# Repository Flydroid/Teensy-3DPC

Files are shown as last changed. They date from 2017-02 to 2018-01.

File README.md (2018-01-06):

# Teensy-3DPC 
is a 3D Printer Controller Board based on the Teensy 3.5 or 3.6.

Schematic and Layout are done in Eagle 

The hardware is still in development and this git used for sharing the development proceess.

#### Contribution to Think3dPrint3d and Esher3d for the DuetWifi Design on which, the Teensy-3DPC is partly based:

"Based on the DuetWifi by Think3dPrint3d and Esher3d, see www.duet3d.com for the original DuetWifi information. This reproduction/modification is not endorsed or supported in any way by Think3dPrint3d or Escher3d".



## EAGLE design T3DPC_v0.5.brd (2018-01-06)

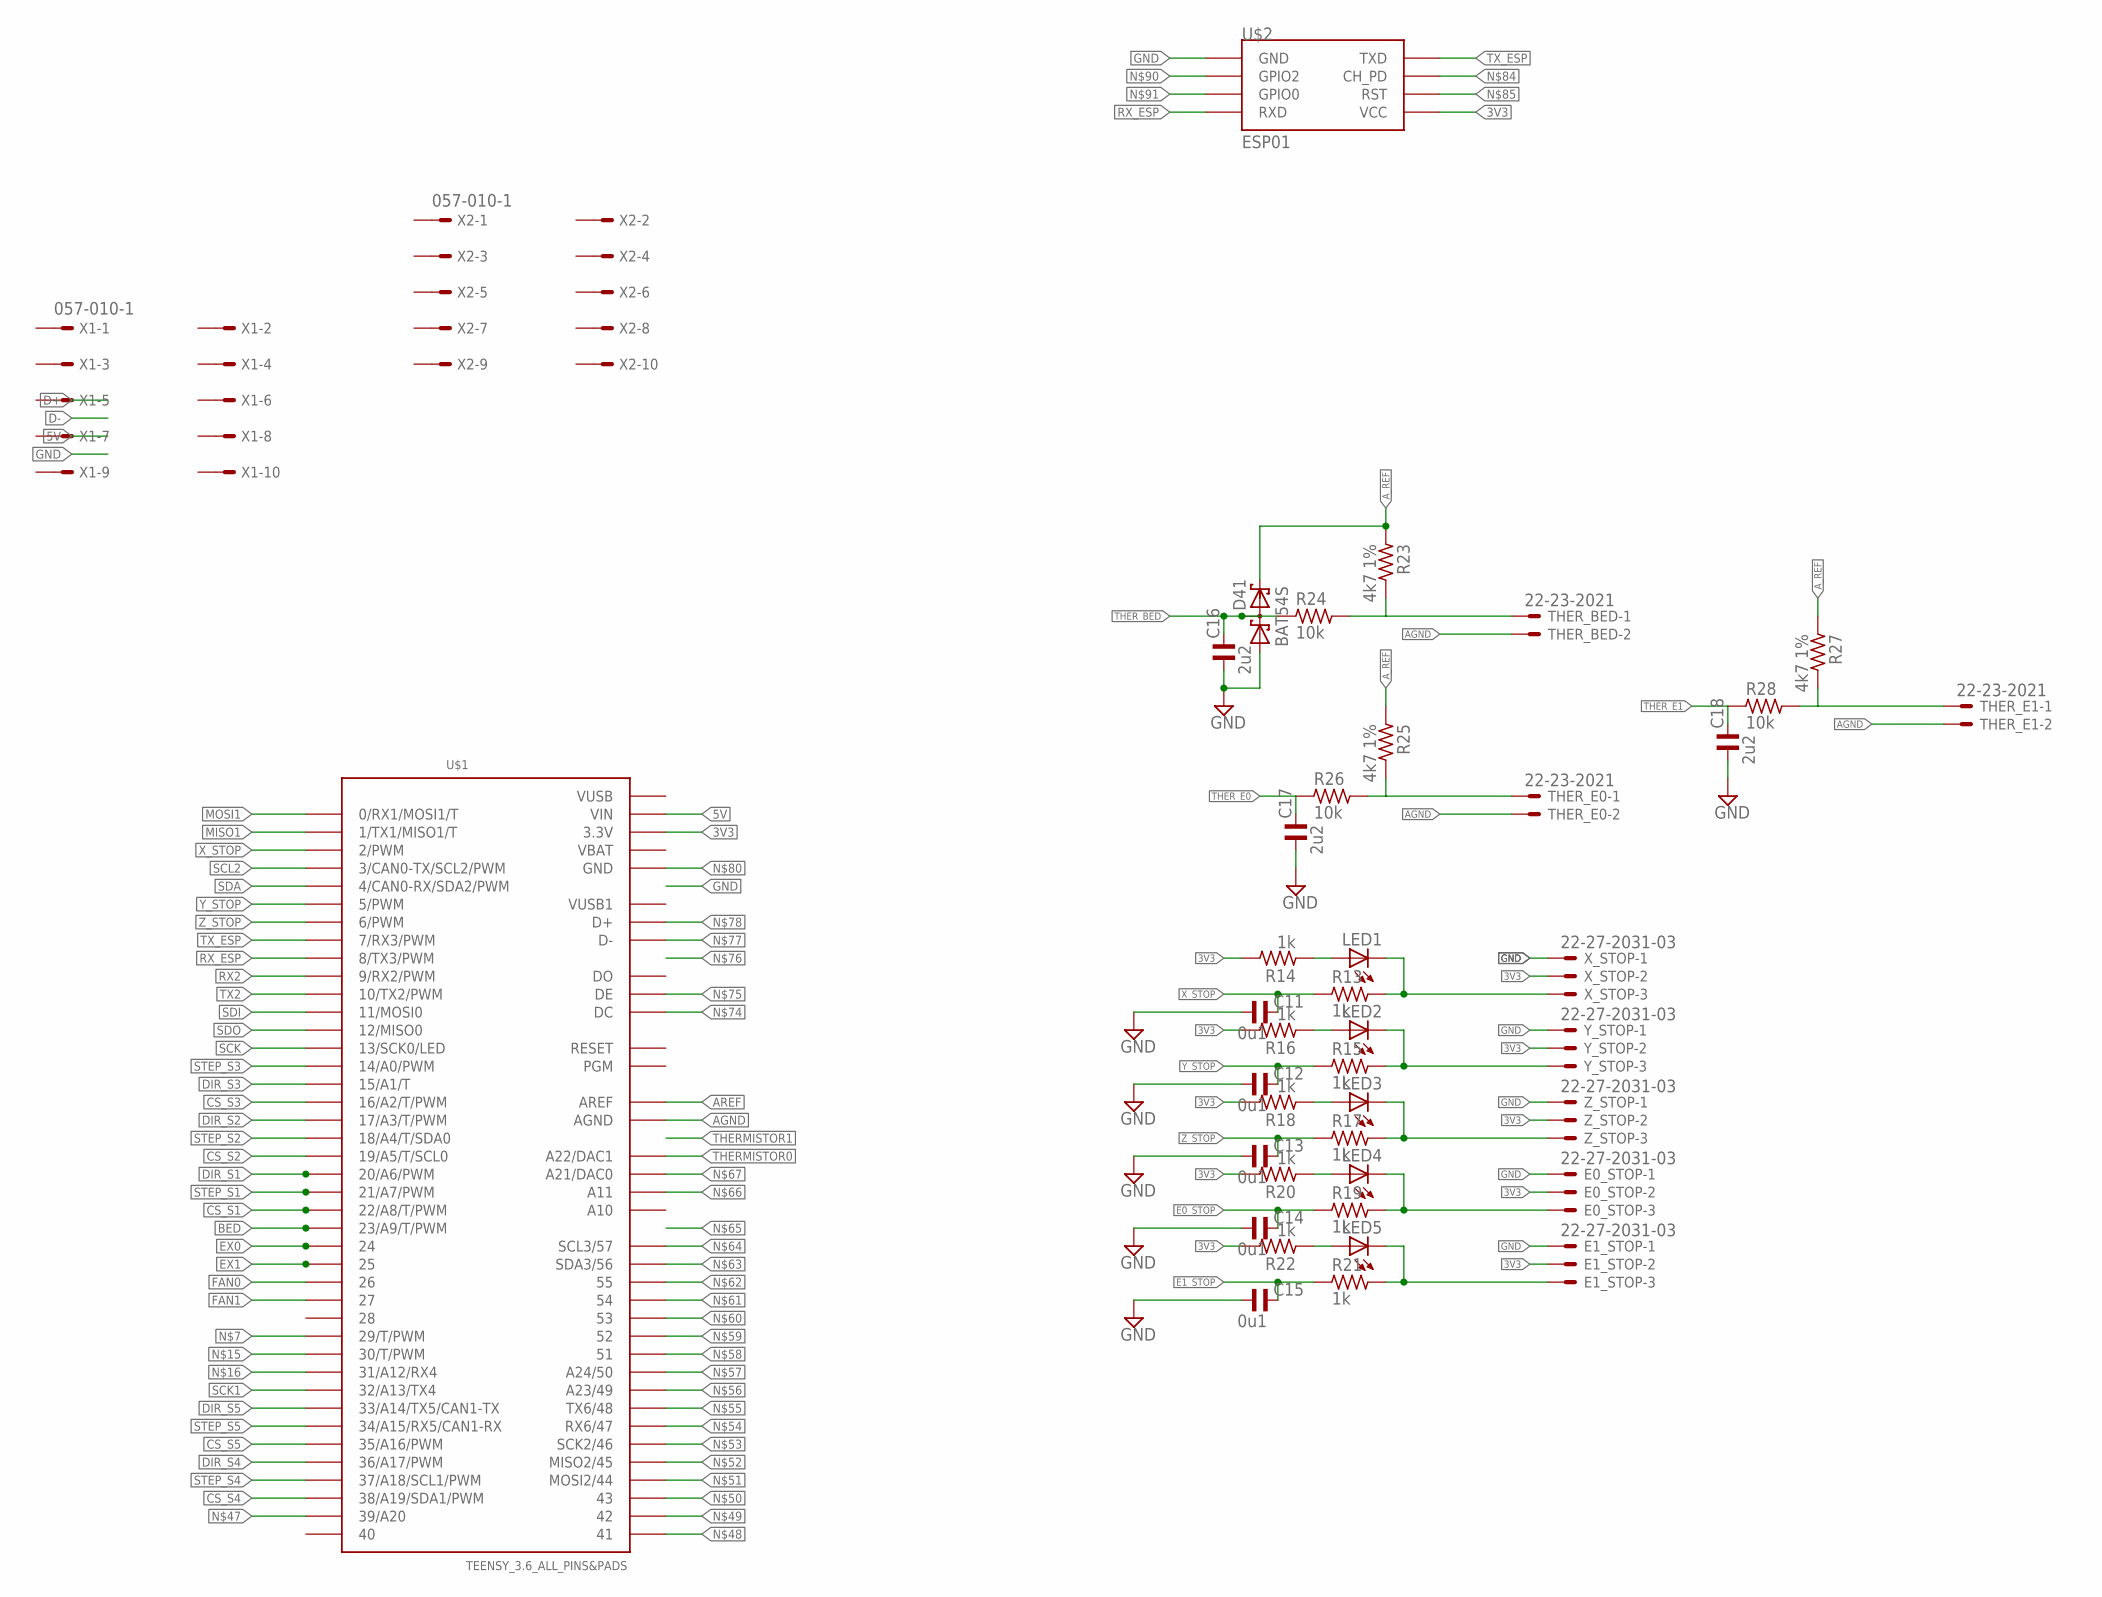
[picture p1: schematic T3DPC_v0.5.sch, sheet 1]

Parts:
C11, C12, C13, C14, C15: 0u1; C0805
C16, C17, C18: 2u2; C0805
D41: BAT54S; SOT23
E0_STOP, E1_STOP: 22-27-2031-03; 6410-03
LED1, LED2, LED3, LED4, LED5: LEDCHIPLED_1206; CHIPLED_1206
R13, R14, R15, R16, R17, R18, R19, R20, R21, R22: 1k; R0805
R23, R25, R27: 4k7 1%; R0805
R24, R26, R28: 10k; R0805
THER_BED: 22-23-2021
THER_E0, THER_E1: 22-23-2021
U$1: TEENSY_3.6_ALL_PINS&PADS
U$2: ESP01
X1, X2: 057-010-1
X_STOP: 22-27-2031-03; 6410-03
Y_STOP: 22-27-2031-03; 6410-03
Z_STOP: 22-27-2031-03; 6410-03

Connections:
3V3: E0_STOP.2, E1_STOP.2, R14.2, R16.2, R18.2, R20.2, R22.2, U$1.3.3V, U$1.3.3V2 (3.3V), U$1.3.3V3 (3.3V), U$1.3.3V4 (3.3V), U$2.VCC, X_STOP.2, Y_STOP.2, Z_STOP.2; also elsewhere on the board
5V: U$1.VIN; also elsewhere on the board
AGND: C16.1, C17.1, C18.1, D41.1 (A1), THER_BED.2, THER_E0.2, THER_E1.2, U$1.AGND
AREF: U$1.AREF
A_REF: D41.2 (C2), R23.1, R25.1, R27.1
BED: U$1.23/A9 (23/A9/T/PWM); also elsewhere on the board
CS_S1: U$1.22/A8 (22/A8/T/PWM); also elsewhere on the board
CS_S2: U$1.19/A5 (19/A5/T/SCL0); also elsewhere on the board
CS_S3: U$1.16/A2 (16/A2/T/PWM); also elsewhere on the board
CS_S4: U$1.38/A19 (38/A19/SDA1/PWM); also elsewhere on the board
CS_S5: U$1.35/A16 (35/A16/PWM); also elsewhere on the board
DIR_S1: U$1.20/A6 (20/A6/PWM); also elsewhere on the board
DIR_S2: U$1.17/A3 (17/A3/T/PWM); also elsewhere on the board
DIR_S3: U$1.15/A1 (15/A1/T); also elsewhere on the board
DIR_S4: U$1.36/A17 (36/A17/PWM); also elsewhere on the board
DIR_S5: U$1.33/A14 (33/A14/TX5/CAN1-TX); also elsewhere on the board
E0_STOP: C14.2, R19.1
E0_STOP_PORT: E0_STOP.3, LED4.C, R19.2
E1_STOP: C15.2, R21.1
E1_STOP_PORT: E1_STOP.3, LED5.C, R21.2
EX0: U$1.24; also elsewhere on the board
EX1: U$1.25; also elsewhere on the board
GND: C11.1, C12.1, C13.1, C14.1, C15.1, E0_STOP.1, E1_STOP.1, U$2.GND, X_STOP.1, Y_STOP.1, Z_STOP.1; also elsewhere on the board
MISO1: U$1.1 (1/TX1/MISO1/T)
MOSI1: U$1.0 (0/RX1/MOSI1/T)
unnamed: LED1.A, R14.1
unnamed: LED2.A, R16.1
unnamed: LED3.A, R18.1
unnamed: LED4.A, R20.1
unnamed: LED5.A, R22.1
unnamed: R25.2, R26.2, THER_E0.1
unnamed: R23.2, R24.2, THER_BED.1
unnamed: R27.2, R28.2, THER_E1.1
unnamed: U$1.GND, U$1.GND1 (GND), U$1.GND2 (GND), U$1.GND3 (GND), U$1.GND4 (GND), U$1.GND5 (GND), U$1.GND6 (GND)
RX2: U$1.9 (9/RX2/PWM)
RX_ESP: U$1.8 (8/TX3/PWM), U$2.RX (RXD)
SCK: U$1.13 (13/SCK0/LED); also elsewhere on the board
SCK1: U$1.32/A13 (32/A13/TX4)
SCL2: U$1.3 (3/CAN0-TX/SCL2/PWM)
SDA: U$1.4 (4/CAN0-RX/SDA2/PWM)
SDI: U$1.11 (11/MOSI0); also elsewhere on the board
SDO: U$1.12 (12/MISO0); also elsewhere on the board
STEP_S1: U$1.21/A7 (21/A7/PWM); also elsewhere on the board
STEP_S2: U$1.18/A4 (18/A4/T/SDA0); also elsewhere on the board
STEP_S3: U$1.14/A0 (14/A0/PWM); also elsewhere on the board
STEP_S4: U$1.37/A18 (37/A18/SCL1/PWM); also elsewhere on the board
STEP_S5: U$1.34/A15 (34/A15/RX5/CAN1-RX); also elsewhere on the board
THERMISTOR0: U$1.A22 (A22/DAC1)
THER_BED: C16.2, D41.3 (C1A2), R24.1
THER_E0: C17.2, R26.1
THER_E1: C18.2, R28.1
TX2: U$1.10 (10/TX2/PWM)
TX_ESP: U$1.7 (7/RX3/PWM), U$2.TX (TXD)
VBAT: U$1.VBAT
VUSB: U$1.VUSB
VUSB1: U$1.VUSB1
X_STOP: C11.2, R13.1, U$1.2 (2/PWM)
X_STOP_PORT: LED1.C, R13.2, X_STOP.3
Y_STOP: C12.2, R15.1, U$1.5 (5/PWM)
Y_STOP_PORT: LED2.C, R15.2, Y_STOP.3
Z_STOP: C13.2, R17.1, U$1.6 (6/PWM)
Z_STOP_PORT: LED3.C, R17.2, Z_STOP.3

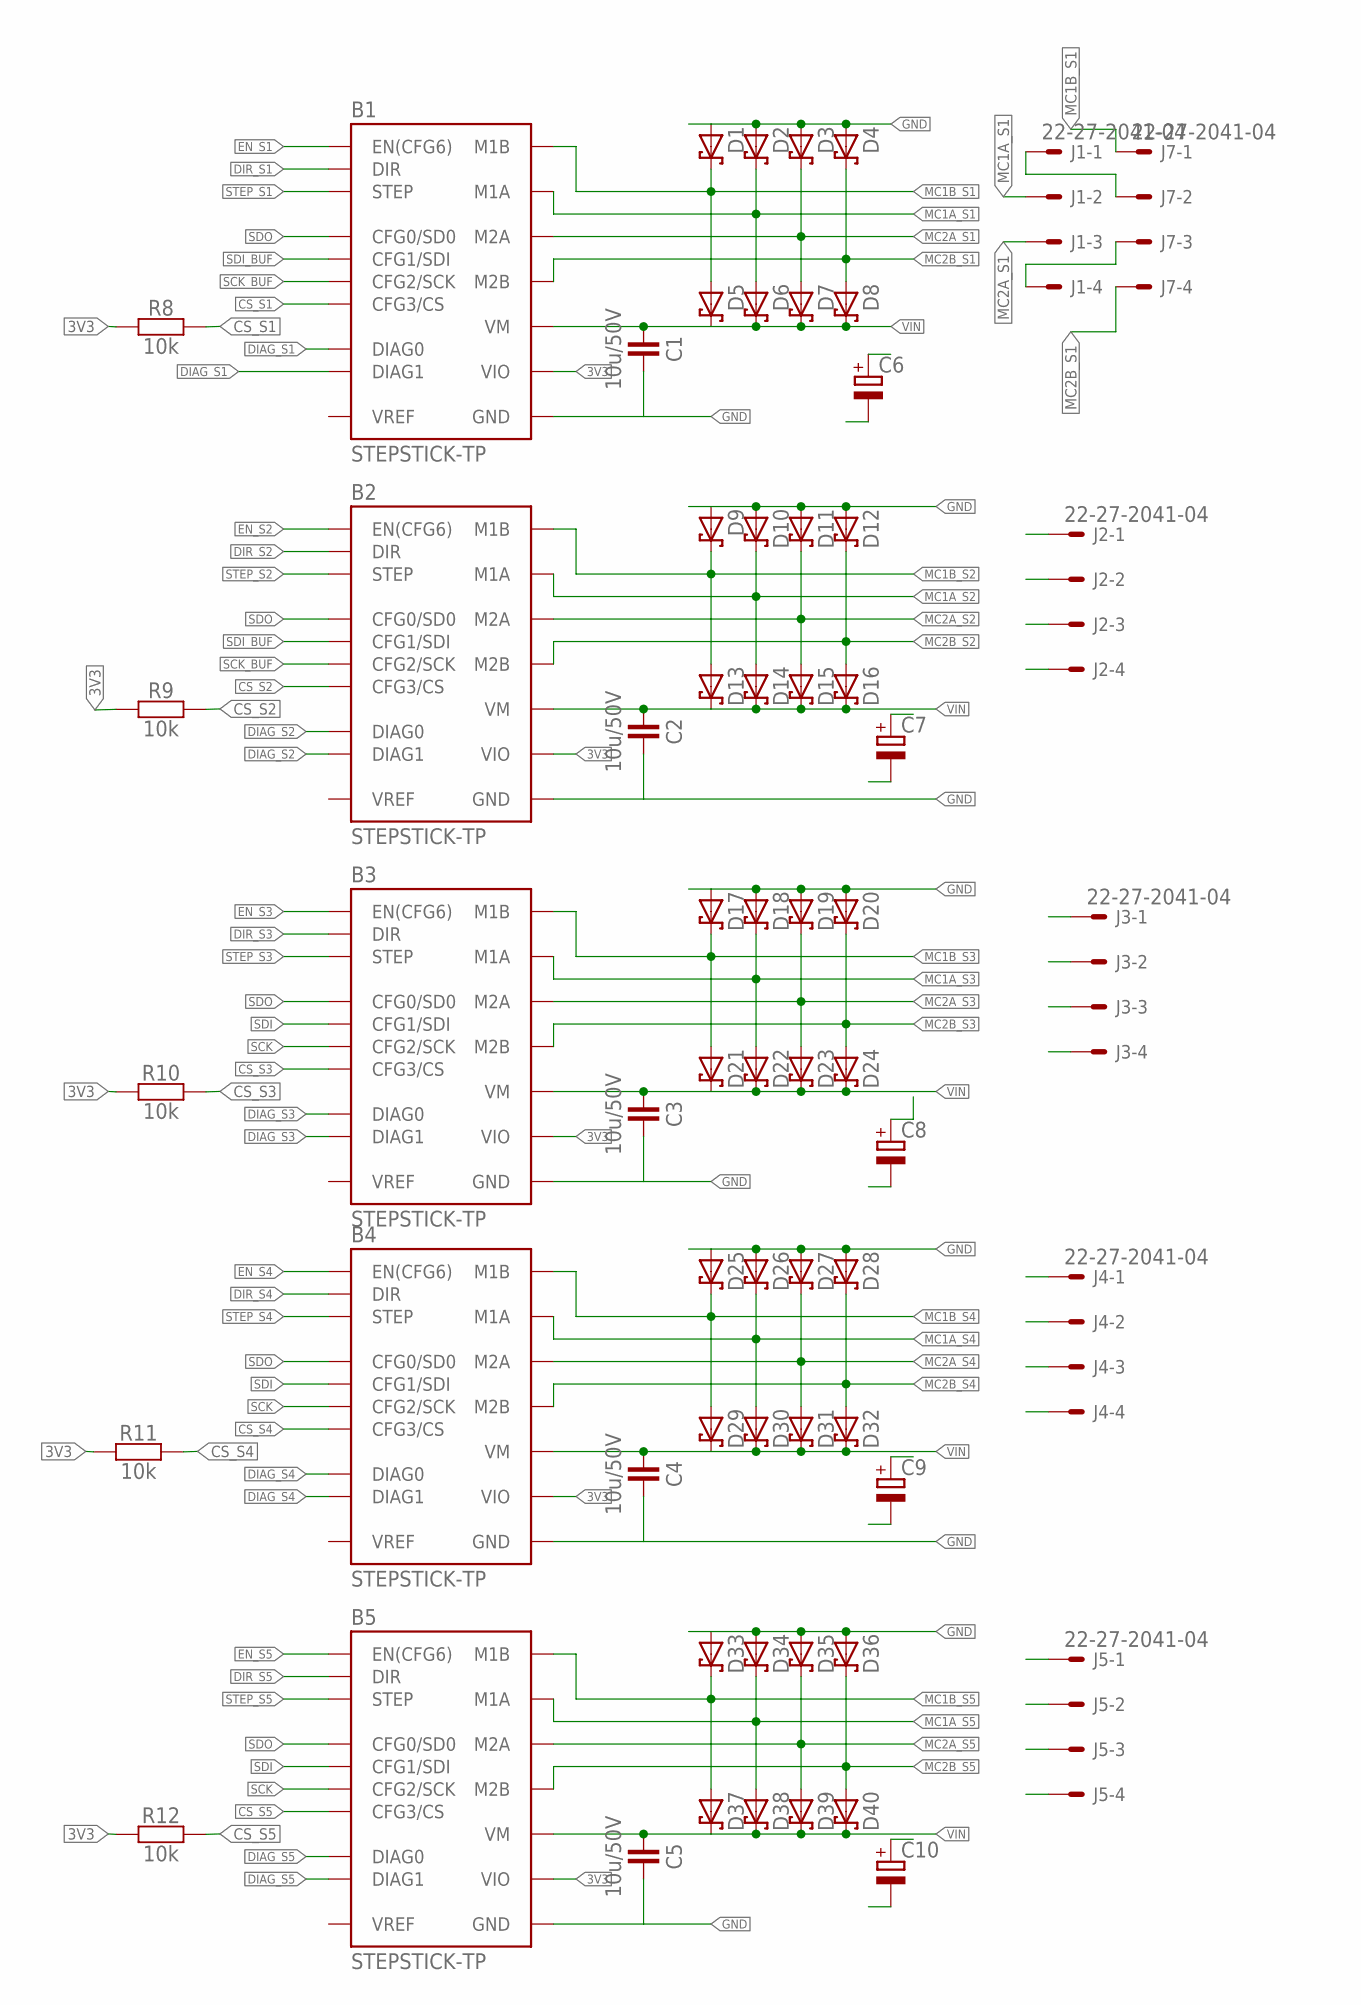
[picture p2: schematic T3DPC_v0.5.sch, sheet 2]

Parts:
B1, B2, B3, B4, B5: STEPSTICK-TP; STEPSTICK_TP
C1, C2, C3, C4, C5: 10u/50V; C1210
C6, C7, C8, C9, C10: CPOL-EU153CLV-0505; 153CLV-0505
D1, D2, D3, D4, D5, D6, D7, D8, D9, D10, D11, D12, D13, D14, D15, D16, D17, D18, D19, D20, D21, D22, D23, D24, D25, D26, D27, D28, D29, D30, D31, D32, D33, D34, D35, D36, D37, D38, D39, D40: D_SCHOTTKY-SMA; SMA_DO214AC
J1, J2, J3, J4, J5, J7: 22-27-2041-04; 6410-04
R8, R9, R10, R11, R12: 10k; C0805

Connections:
3V3: B1.VIO, B2.VIO, B3.VIO, B4.VIO, B5.VIO, R8.1, R9.1, R10.1, R11.1, R12.1; also elsewhere on the board
CS_S1: B1.CFG3 (CFG3/CS), R8.2; also elsewhere on the board
CS_S2: B2.CFG3 (CFG3/CS), R9.2; also elsewhere on the board
CS_S3: B3.CFG3 (CFG3/CS), R10.2; also elsewhere on the board
CS_S4: B4.CFG3 (CFG3/CS), R11.2; also elsewhere on the board
CS_S5: B5.CFG3 (CFG3/CS), R12.2; also elsewhere on the board
DIAG_S1: B1.DIAG0, B1.DIAG1
DIAG_S2: B2.DIAG0, B2.DIAG1
DIAG_S3: B3.DIAG0, B3.DIAG1
DIAG_S4: B4.DIAG0, B4.DIAG1
DIAG_S5: B5.DIAG0, B5.DIAG1
DIR_S1: B1.DIR; also elsewhere on the board
DIR_S2: B2.DIR; also elsewhere on the board
DIR_S3: B3.DIR; also elsewhere on the board
DIR_S4: B4.DIR; also elsewhere on the board
DIR_S5: B5.DIR; also elsewhere on the board
EN_S1: B1.EN (EN(CFG6))
EN_S2: B2.EN (EN(CFG6))
EN_S3: B3.EN (EN(CFG6))
EN_S4: B4.EN (EN(CFG6))
EN_S5: B5.EN (EN(CFG6))
GND: B1.GND@1 (GND), B1.GND@2 (GND), B2.GND@1 (GND), B2.GND@2 (GND), B3.GND@1 (GND), B3.GND@2 (GND), B4.GND@1 (GND), B4.GND@2 (GND), B5.GND@1 (GND), B5.GND@2 (GND), C1.2, C2.2, C3.2, C4.2, C5.2, C6.-, C7.-, C8.-, C9.-, C10.-, D1.A, D2.A, D3.A, D4.A, D9.A, D10.A, D11.A, D12.A, D17.A, D18.A, D19.A, D20.A, D25.A, D26.A, D27.A, D28.A, D33.A, D34.A, D35.A, D36.A; also elsewhere on the board
MC1A_S1: B1.M1A, D2.C, D6.A, J1.2
MC1A_S2: B2.M1A, D10.C, D14.A, J2.2
MC1A_S3: B3.M1A, D18.C, D22.A, J3.2
MC1A_S4: B4.M1A, D26.C, D30.A, J4.2
MC1A_S5: B5.M1A, D34.C, D38.A, J5.2
MC1B_S1: B1.M1B, D1.C, D5.A, J7.1
MC1B_S2: B2.M1B, D9.C, D13.A, J2.1
MC1B_S3: B3.M1B, D17.C, D21.A, J3.1
MC1B_S4: B4.M1B, D25.C, D29.A, J4.1
MC1B_S5: B5.M1B, D33.C, D37.A, J5.1
MC2A_S1: B1.M2A, D3.C, D7.A, J1.3
MC2A_S2: B2.M2A, D11.C, D15.A, J2.3
MC2A_S3: B3.M2A, D19.C, D23.A, J3.3
MC2A_S4: B4.M2A, D27.C, D31.A, J4.3
MC2A_S5: B5.M2A, D35.C, D39.A, J5.3
MC2B_S1: B1.M2B, D4.C, D8.A, J7.4
MC2B_S2: B2.M2B, D12.C, D16.A, J2.4
MC2B_S3: B3.M2B, D20.C, D24.A, J3.4
MC2B_S4: B4.M2B, D28.C, D32.A, J4.4
MC2B_S5: B5.M2B, D36.C, D40.A, J5.4
unnamed: J1.4, J7.3
unnamed: J1.1, J7.2
SCK: B3.CFG2 (CFG2/SCK), B4.CFG2 (CFG2/SCK), B5.CFG2 (CFG2/SCK); also elsewhere on the board
SCK_BUF: B1.CFG2 (CFG2/SCK), B2.CFG2 (CFG2/SCK)
SDI: B3.CFG1 (CFG1/SDI), B4.CFG1 (CFG1/SDI), B5.CFG1 (CFG1/SDI); also elsewhere on the board
SDI_BUF: B1.CFG1 (CFG1/SDI), B2.CFG1 (CFG1/SDI)
SDO: B1.NC/CFG0 (CFG0/SD0), B2.NC/CFG0 (CFG0/SD0), B3.NC/CFG0 (CFG0/SD0), B4.NC/CFG0 (CFG0/SD0), B5.NC/CFG0 (CFG0/SD0); also elsewhere on the board
STEP_S1: B1.STEP; also elsewhere on the board
STEP_S2: B2.STEP; also elsewhere on the board
STEP_S3: B3.STEP; also elsewhere on the board
STEP_S4: B4.STEP; also elsewhere on the board
STEP_S5: B5.STEP; also elsewhere on the board
VIN: B1.VM, B2.VM, B3.VM, B4.VM, B5.VM, C1.1, C2.1, C3.1, C4.1, C5.1, C6.+, C7.+, C8.+, C9.+, C10.+, D5.C, D6.C, D7.C, D8.C, D13.C, D14.C, D15.C, D16.C, D21.C, D22.C, D23.C, D24.C, D29.C, D30.C, D31.C, D32.C, D37.C, D38.C, D39.C, D40.C; also elsewhere on the board

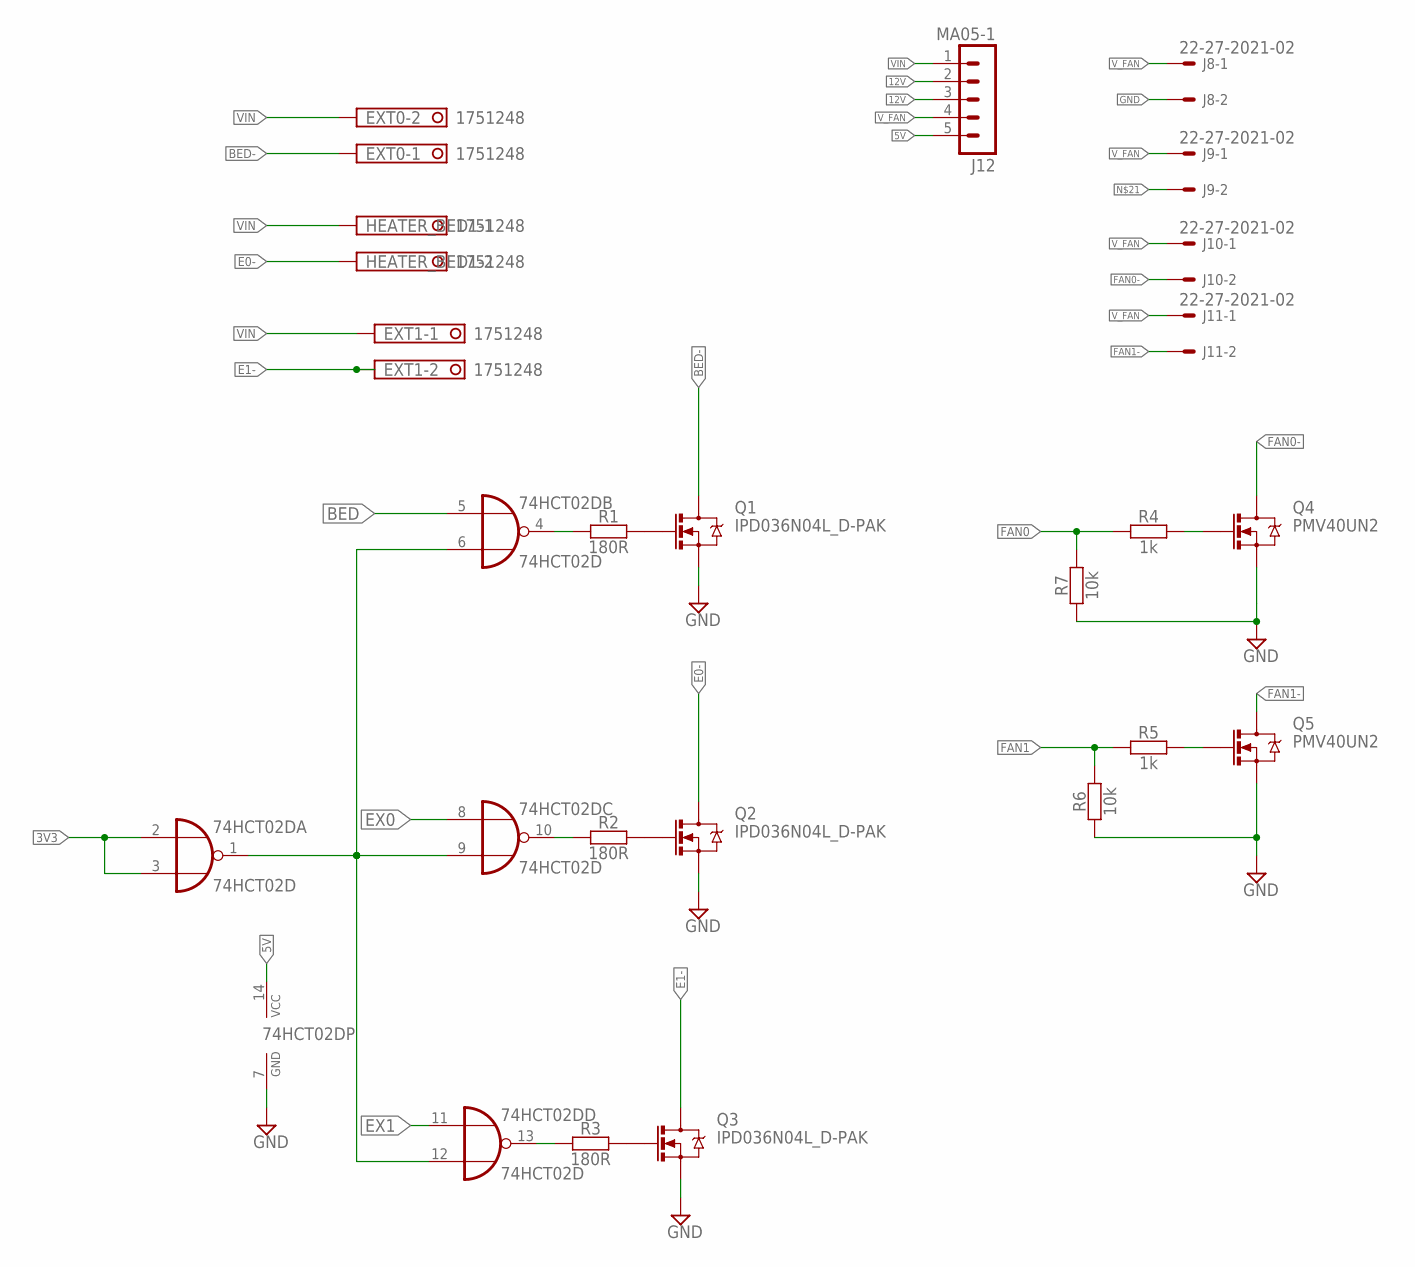
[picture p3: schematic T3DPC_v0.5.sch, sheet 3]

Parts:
74HCT02D: 74HCT02D; SO14
EXT0, EXT1: 1751248
HEATER_BED1: 1751248
J8, J9, J10, J11: 22-27-2021-02; 6410-02
J12: MA05-1
Q1, Q2, Q3: IPD036N04L_D-PAK; D-PAK_TO252AA
Q4, Q5: PMV40UN2; SOT23-3
R1, R2, R3: 180R; C0805
R4, R5: 1k; C0805
R6, R7: 10k; C0805

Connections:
3V3: 74HCT02D.2 (I0), 74HCT02D.3 (I1); also elsewhere on the board
5V: 74HCT02D.14 (VCC), J12.5; also elsewhere on the board
12V: J12.2, J12.3; also elsewhere on the board
BED: 74HCT02D.5 (I0); also elsewhere on the board
BED-: EXT0.1, Q1.2 (D)
E0-: HEATER_BED1.2, Q2.2 (D)
E1-: EXT1.2, Q3.2 (D)
EX0: 74HCT02D.8 (I0); also elsewhere on the board
EX1: 74HCT02D.11 (I0); also elsewhere on the board
FAN0: R4.1, R7.2
FAN0-: J10.2, Q4.3 (D)
FAN1: R5.1, R6.2
FAN1-: J11.2, Q5.3 (D)
GND: 74HCT02D.7 (GND), J8.2, Q1.3 (S), Q2.3 (S), Q3.3 (S), Q4.2 (S), Q5.2 (S), R6.1, R7.1; also elsewhere on the board
unnamed: Q1.1 (G), R1.2
unnamed: Q2.1 (G), R2.2
unnamed: Q3.1 (G), R3.2
unnamed: 74HCT02D.4 (O), R1.1
unnamed: 74HCT02D.10 (O), R2.1
unnamed: 74HCT02D.13 (O), R3.1
unnamed: 74HCT02D.1 (O), 74HCT02D.6 (I1), 74HCT02D.9 (I1), 74HCT02D.12 (I1)
unnamed: Q4.1 (G), R4.2
unnamed: Q5.1 (G), R5.2
VIN: EXT0.2, EXT1.1, HEATER_BED1.1, J12.1; also elsewhere on the board
V_FAN: J8.1, J9.1, J10.1, J11.1, J12.4

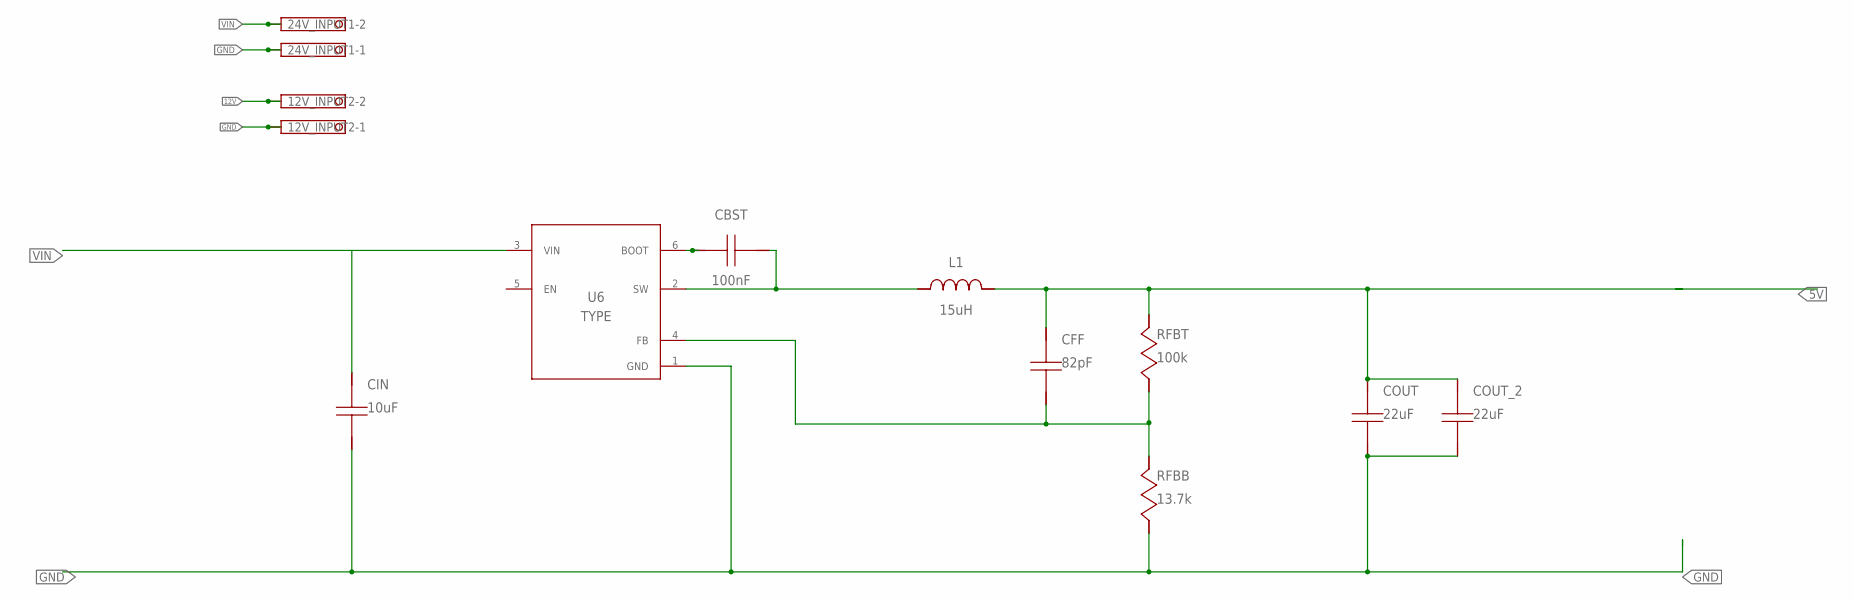
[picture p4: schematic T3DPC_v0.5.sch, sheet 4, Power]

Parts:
12V_INPUT2, 24V_INPUT1: 1751248
CBST: 100nF; 0805
CFF: 82pF; 0805
CIN: 10uF; 1206_180
COUT: 22uF; 1812
COUT_2: 22uF; 1812
L1: 15uH; VLP8040
RFBB: 13.7k; 0805
RFBT: 100k; 0805
U6: Value; DDC0006A_N

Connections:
1: CBST.1, U6.6 (BOOT)
2: CFF.2, RFBB.1, RFBT.2, U6.4 (FB)
3: CBST.2, L1.1, U6.2 (SW)
5V: CFF.1, COUT.1, COUT_2.1, L1.2, RFBT.1; also elsewhere on the board
12V: 12V_INPUT2.2; also elsewhere on the board
GND: 12V_INPUT2.1, 24V_INPUT1.1, CIN.2, COUT.2, COUT_2.2, RFBB.2, U6.1 (GND); also elsewhere on the board
VIN: 24V_INPUT1.2, U6.3 (VIN); also elsewhere on the board

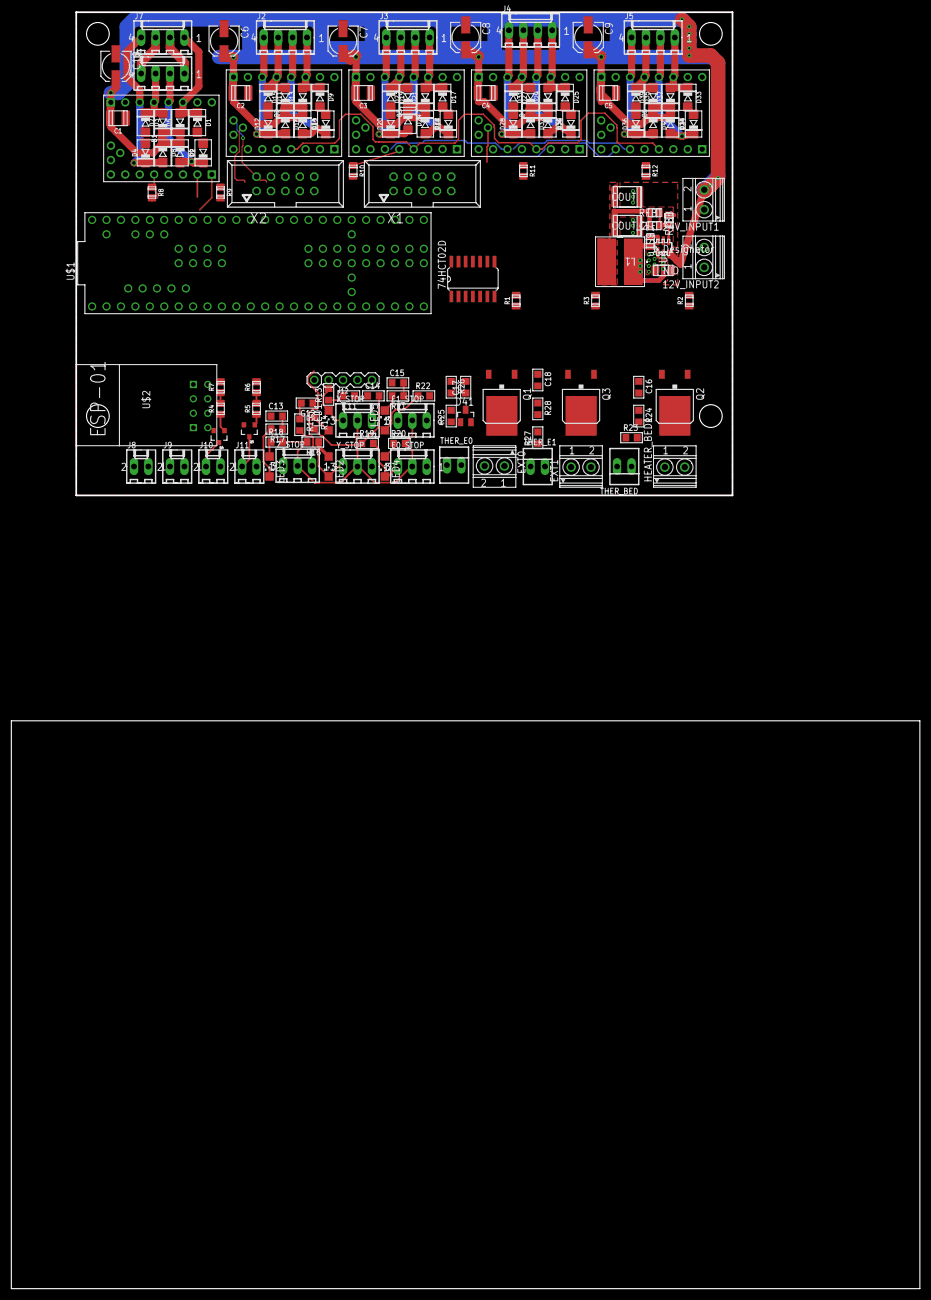
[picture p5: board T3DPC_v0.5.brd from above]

Board: 2 copper layers, 115.6 x 85.1 mm, 140 parts (0 on the bottom side), 101 nets.

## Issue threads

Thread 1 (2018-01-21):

Active?

boelle, 2018-01-21:
Hi

I came across your board as i was thinking of using a teensy for my 500mm3 core xy printer

wanted to ask if you are working on it active? i have also asked the people behind repetier firmware if they plan to support the teensy 3.6

i do not like marlin that much, they have a mile long issue list and the dev people seems to only be open to input from an "inner circle" but that could be just me.

Closed 2018-01-21.

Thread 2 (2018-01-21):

Proposed Change: Move power input closer to heatbed terminals

boelle, 2018-01-21:
the closer the input terminals are to output the better

while on terminals make sure they can handle about 15A just to be on the safe side

and for FET's pick ones that has as low on resistance as possible, it will make them run cooler

Flydroid, 2018-01-21:
I'm a bit on and off with the development as I have some other projects at the same time and currently no 3D Printer which needs a new board. I love the Teensy boards and a 3D printer controller is still missing in its repertoire, so I wanted to design a board using modern features like TMC2130 and still be kind of cost effective. As I realized this might not be the case with a 25-30$ MCU and 10$ stepper boards, i was a bit conflicted with the overall design decision to use so many daughter boards.

The mosfet design is based on the Duet WIFI, which I trust has made very good design choices.
Another thing I looking for input is fusing? I have seen the automotive fuses on ramps boards - I generally would put the fuses beside the PCB using standard fuse holders.

boelle, 2018-01-21:
the automotive fuses are a great idea... the RADDS board for the DUE board uses them too

i think tom sanladerer  said they are far better than the standard poly fuses

since you are at the beginning try and go for the mini fuses

as for the cost... i would pick your design over the duet or smoothie for the simple reason that i can change out a stepper driver if i blown one

i can do the same with the duet, but i will be forced to use an external driver and it will clutter things

Closed 2019-03-19.

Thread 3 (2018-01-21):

IDEA: Support analog probes

boelle, 2018-01-21:
since we have a fast cpu it might make a bit sense to support analog probes like the mini ir touch sensor

https://miscsolutions.wordpress.com/mini-height-sensor-board/

it can be debated if it makes it any better, but my argument would be that an analog value can be used to make a more precise detection. in some cases you have to make the probing speed slower. this depends on how fast the cpu can cope with the analog voltage and move the stepper at the same time

while on probes make sure to include at least one servo connector so probes like bl touch can be used

Flydroid, 2018-01-21:
That just the feedback I need! I was still figuring out which features the board should support and which pins are needed. As the bottom pins of the 3.5/3.6 are a bit hard to reach I'm not sure yet if i will include them. Probably some testing is needed.
Generally want to route out every available pin.

boelle, 2018-01-21:
i'm good at getting ideas, but i lack the skill of creating them

i can do basic layout in eagle but other than that i'm a noob :-D

if you can route a pin and its not in use at least make a hole where people can solder in a wire or put in a single pin header thingy

Closed 2019-03-19.

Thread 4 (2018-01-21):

Proposed Change: add a 2nd Z endstop input

boelle, 2018-01-21:
this is just if there are enough spare pins and it does not make it harder to route tracks

the point is that the printer can automatic sync individual Z steppers if they have an endstop each

one could say that some of the not used endstops can be used for this

this of course puts up the next question, what are the max endstops used for on a 3d printer? i have never seen max endstops used

i'm building a hypercube evolution and it has max endstops on X and Y but i have a hard time to figure what they are good for

Flydroid, 2018-01-21:
Yes, usually 3D Printers only have one end stop for each axis for a repeatable definite position from which every thing is referenced.
Even if you have several Z steppers, aren't they connected mechanically and thus only on end stop is needed?

boelle, 2018-01-21:
no, not excatly

i'm building this one: https://www.thingiverse.com/thing:2254103

the version to the right on the  picture has 2 z steppers and they can get out of sync

also printers like prusa i3 have 2 z steppers but connected to same stepper driver.

my idea is to have each stepper motor on individual stepper drivers and each stepper motor has it own endstop.

With repetier firmware (and marlin too i think) when you send G28 Z both steppers go to endstop, but if one Z stepper homes a little before the other it will stop

when both are homed they will be in sync

hope it made sense??

Closed 2019-03-19.

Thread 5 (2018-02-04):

IDEA: Base layout on RAMPS 1.4.2

boelle, 2018-02-04:
Not sure if you like the idea but i was boared and thought if it would not be faster to base the board partly on the Ramps 1.4.2

http://reprap.org/wiki/RAMPS_1.4#RAMPS_1.4.2

i could try and have a go at it starting by adding a way to connect the teensy to it instead of a mega board

thoughts?

boelle, 2018-02-05:
so far i have managed to replace the std. stepsticks with 2130 ones (Y and Z pending)

i have not included the spi bus yet as i want to judge how easy it would be

Flydroid, 2018-02-05:
You could do that, but wiring in the Teensy is just as much work as starting out fresh. You could use parts of the ramps design for example the heater mosfet schematic.

Or did you want to put the Teensy on a breakout for the MEGA layout -> https://forum.pjrc.com/threads/36244-Teensy-3-5-3-6-Breakout-board-to-test-things-with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
Then you could just use the ramps with a Teensy, but no special TMC2130 functions if you don't redo the RAMPS board aswell.

boelle, 2018-02-05:
hmm... will have to thinker a bit

thanks for the input... food for thought

boelle, 2018-02-05:
have asked for the sources for that teensy breakout

and during the morning i have partly reworked the ramps board so now it has tmc2130 sockets, just need to figure how to do the spi bus...

i'm open to that you are right that it might be faster to do from scratch

boelle, 2018-02-05:
i got the spi added to except the CS lines

so from your org list i have:

- Dual automotive fuses

- LCD Addon compatible

what i miss are:

- check that everything can work with 3.3 level signal

- add endstop input protection

- figure how to add CS lines

- pt100/thermocouple

there are allready caps on the endstop input's but i assume that you are thinking reverse connection projection?

Closed 2019-03-19.

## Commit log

2017-02-06 update schematic and board layout
    [T3DPC_v0.2.brd, T3DPC_v0.2.sch]
2018-01-06 Update Schematics and Layout
    [T3DPC_v0.5.brd, T3DPC_v0.5.sch]

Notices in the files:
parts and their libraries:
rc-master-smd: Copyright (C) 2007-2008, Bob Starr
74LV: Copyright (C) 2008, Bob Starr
